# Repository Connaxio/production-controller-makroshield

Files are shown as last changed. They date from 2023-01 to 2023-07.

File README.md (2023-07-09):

# Production Controller makroShield
The Production Controller makroShield (PCM) is a modular controller designed to operate 24 V devices with the help of connected and remote sensors.

The PCM has a mikroBUS socket that works with Espoir, our Power over Ethernet devboard, to provide remote control, as well as advanced functionalities through node-red and Home Assistant. Simpler control can be achieved by directly programming Espoir.

Originally designed to operate greenhouses and irrigation valves, it can be adapted to many different kinds of small productions and climate control due to its modular nature.

2 drivers are available with the PCM: a 2-ways driver for bidirectional motors, and a 1-way, AC/DC controller for other devices, like valves, fans, and unidirectional motors. Up to 15 drivers can be connected simultaneously, and scheduled to use up to 350 Watts of power at a time.

Being modular makes the PCM easy to repair and upgrade, and helps reduce cost for smaller operations.

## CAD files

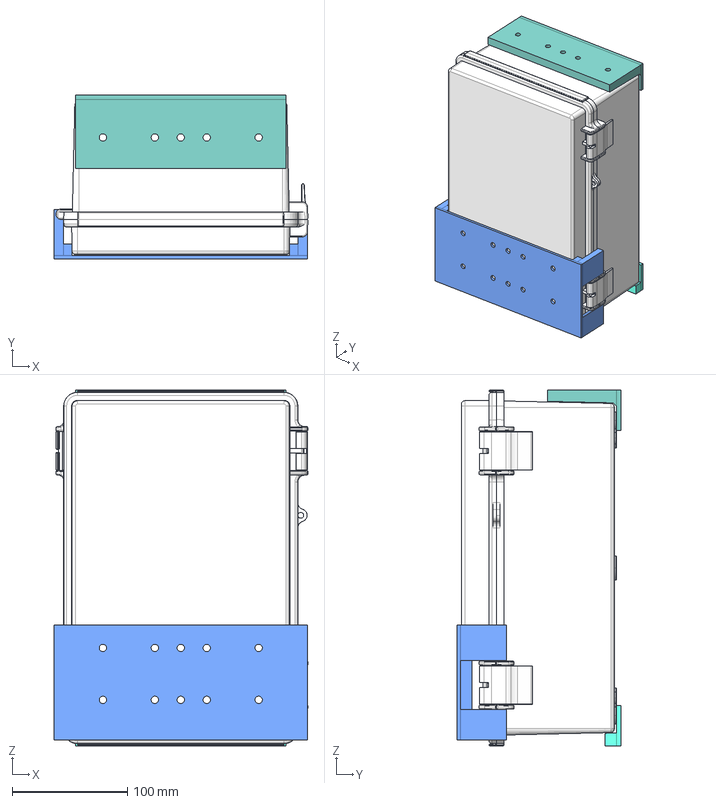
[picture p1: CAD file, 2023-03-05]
3d/piercing_guide.FCStd
219.9 x 142.5 x 308.6 mm
Latch-med-4mm
Latch-med-4mm001
NBF-32016-B
NBF-32016-C

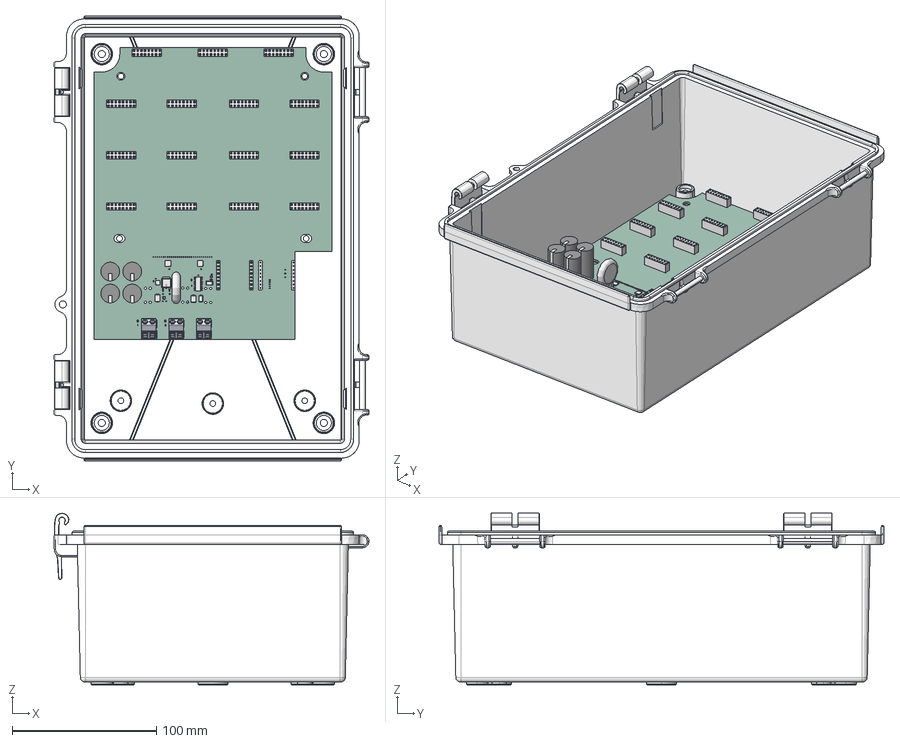
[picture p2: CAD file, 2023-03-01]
3d/3d_fit.FCStd
218.4 x 308.6 x 119.0 mm
Latch-med-4mm
Latch-med-4mm001
NBF-32016-B
production_controller_makroshield PCB

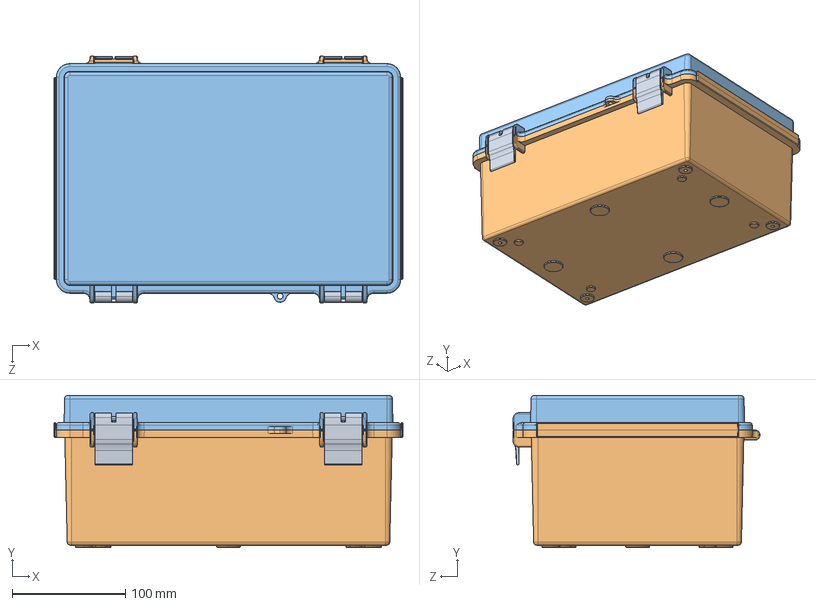
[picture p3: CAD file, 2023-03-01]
3d/NBF-32016.STEP
308.6 x 134.5 x 218.4 mm
Latch-med-4mm x 2
NBF-32016-B
NBF-32016-C

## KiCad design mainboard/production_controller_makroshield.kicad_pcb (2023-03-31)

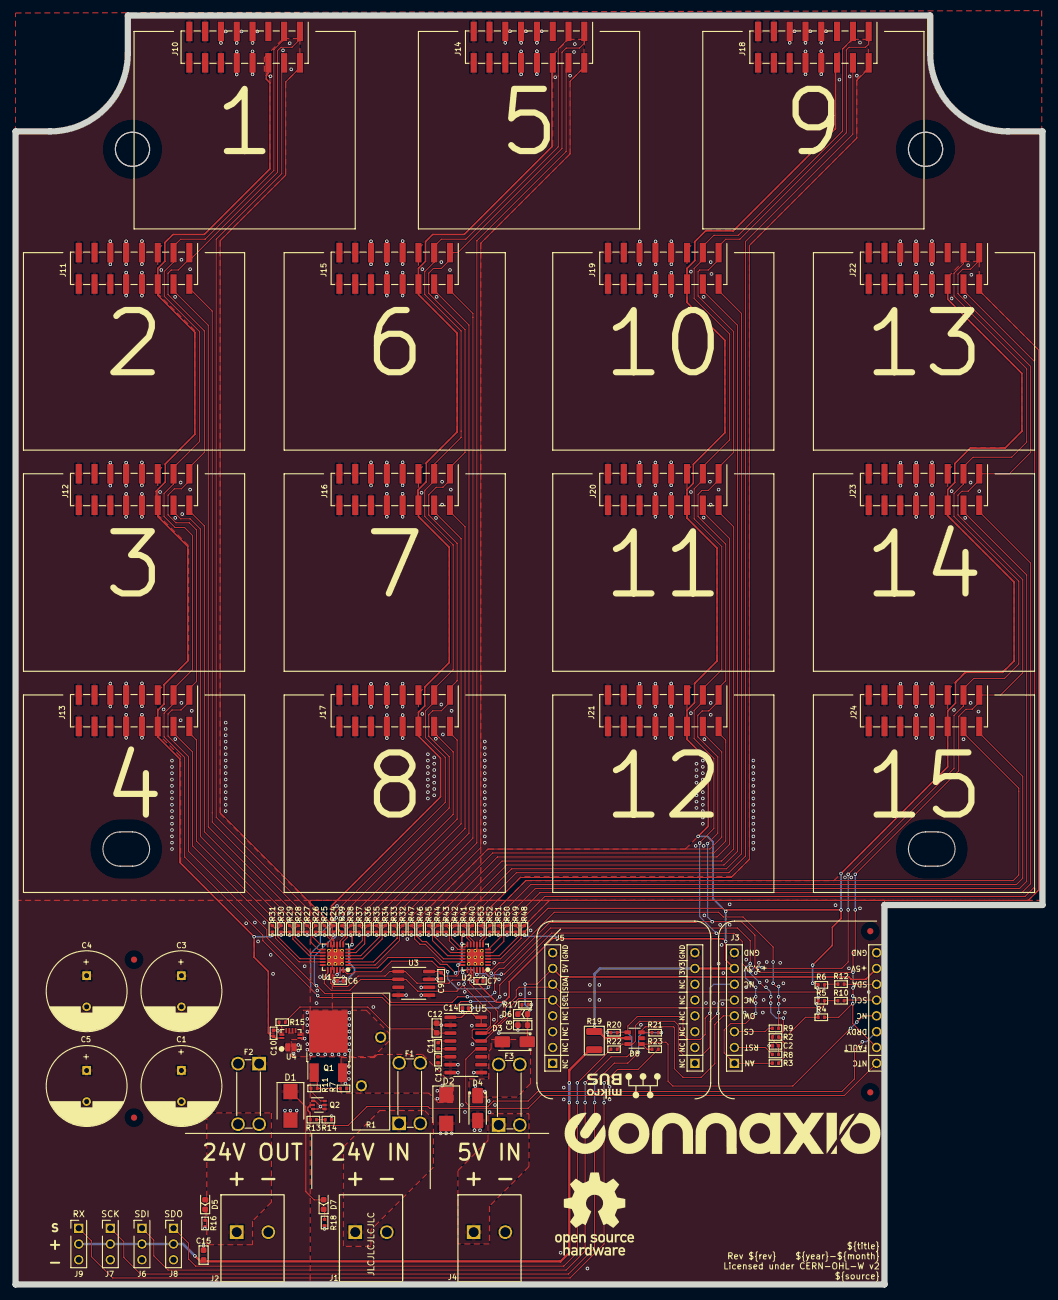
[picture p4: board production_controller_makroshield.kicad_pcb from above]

Board: 2 copper layers, 165.1 x 204.0 mm, 118 parts (1 on the bottom side), 72 nets.

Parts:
C1, C3, C4, C5: CAP_AE_1MF_50V_TH_12.5MM; CAPAE_RAD_D12.5_H26.5_P5
C2, C6, C7, C9, C10, C11, C13, C14: CAP_CER_100NF_25V_0402; CAP_CER_0402_1005M
C8, C12, C15: CAP_CER_22UF_10V_0603; CAP_CER_0603_1608M
D1, D2: DIO_TVS_24V_UNI_SMB; DO-124AA_SMB
D3: DIO_SBD_100V_3A_SMA; DO-214AC_SMA
D4: DIO_TVS_5V_UNI_SMA; DO-214AC_SMA
D5, D6, D7: DIO_LED_GREEN_150060GS75000; LED_0603_1608M
D8: DIO_TVS_SRV05-4HTG; SOT-23-6
F1, F2, F3: FUS_BLADE_MINI_3588-1
F4, F5, F6, F7: FID_1X3
J1, J2, J4: CON_TERM_BLK_1X2_TB008A-508-02BE
J3: CON_HDR_MIKROBUS_ADDON_TH
J5: CON_HDR_MIKROBUS_SOCKET_TH
J6, J7, J8, J9: CON_HDR_100MILS_M_TH_1X3
J10, J11, J12, J13, J14, J15, J16, J17, J18, J19, J20, J21, J22, J23, J24: CON_CONNAXIO_MOTOR_DRIVER
MTH1, MTH2: MTH_M5_NPTH
MTH3, MTH4: MTH_SLOT_M5_2MM_NPTH
Q1: TRX_PMOS_AOD4189; TO-252-3
Q2: TRX_2NPN_BC846S,115; SOT-363_SC-70-6
R1: NTC_SL22 2R018; RV_DISC_D22_W6_P7.8
R2, R3, R4, R7, R11, R13, R14, R24, R25, R26, R27, R28, R29, R30, R31, R32, R33, R34, R35, R36, R37, R38, R39, R40, R41, R42, R43, R44, R45, R46, R47, R48, R49, R50, R51, R52, R53: RES_12.4KΩ_1%_0402; RES_0402_1005M
R5, R6, R15, R16, R18: RES_5.10KΩ_1%_0402; RES_0402_1005M
R8, R9, R10, R12, R20, R21, R22, R23: RES_226Ω_1%_0402; RES_0402_1005M
R17: RES_1.00KΩ_1%_0402; RES_0402_1005M
R19: PTC_SMD1210B010TF; RES_1210_3225M
U1, U2: IO_EXP_PI4IOE5V6416ZDEX; QFN-24_4x4_P0.5_EP2.7X2.7
U3: SEN_TEMP_TMP1075DR; SOIC-8_3.9x4.9_P1.27
U4: SEN_CUR_ACS711KEXLT-31AB-T; QFN-12_CUR_SEN_ACS7
U5: ADC_NAU7802SGI; SOIC-16_3.9X9.9_P1.27

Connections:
+3.3V: C6.1, C7.1, C9.1, C10.1, C14.1, D8.5, J3.7 (+3.3V), J5.7 (+3.3V), J10.6 (3.3V), J11.6 (3.3V), J12.6 (3.3V), J13.6 (3.3V), J14.6 (3.3V), J15.6 (3.3V), J16.6 (3.3V), J17.6 (3.3V), J18.6 (3.3V), J19.6 (3.3V), J20.6 (3.3V), J21.6 (3.3V), J22.6 (3.3V), J23.6 (3.3V), J24.6 (3.3V), R2.1, R3.1, R4.1, R5.1, R6.1, R19.1, R24.1, R25.1, R26.1, R27.1, R28.1, R29.1, R30.1, R31.1, R32.1, R33.1, R34.1, R35.1, R36.1, R37.1, R38.1, R39.1, R40.1, R41.1, R42.1, R43.1, R44.1, R45.1, R46.1, R47.1, R48.1, R49.1, R50.1, R51.1, R52.1, R53.1, U1.21 (VDDP), U1.23 (VDDI2C), U2.18 (ADDR), U2.21 (VDDP), U2.23 (VDDI2C), U3.8 (V+), U4.12 (VCC), U5.1 (REFP), U5.15 (DVDD), U5.16 (AVDD)
+5V: C8.1, D3.1 (K), D6.2 (A), J3.15 (+5V), J5.15 (+5V)
+24VDC: C1.1, C3.1, C4.1, C5.1, D1.1 (K), D7.2 (A), F2.1, F2.2, J10.12 (VDrive), J10.13 (VDrive), J10.14 (VDrive), J10.15 (VDrive), J10.16 (VDrive), J11.12 (VDrive), J11.13 (VDrive), J11.14 (VDrive), J11.15 (VDrive), J11.16 (VDrive), J12.12 (VDrive), J12.13 (VDrive), J12.14 (VDrive), J12.15 (VDrive), J12.16 (VDrive), J13.12 (VDrive), J13.13 (VDrive), J13.14 (VDrive), J13.15 (VDrive), J13.16 (VDrive), J14.12 (VDrive), J14.13 (VDrive), J14.14 (VDrive), J14.15 (VDrive), J14.16 (VDrive), J15.12 (VDrive), J15.13 (VDrive), J15.14 (VDrive), J15.15 (VDrive), J15.16 (VDrive), J16.12 (VDrive), J16.13 (VDrive), J16.14 (VDrive), J16.15 (VDrive), J16.16 (VDrive), J17.12 (VDrive), J17.13 (VDrive), J17.14 (VDrive), J17.15 (VDrive), J17.16 (VDrive), J18.12 (VDrive), J18.13 (VDrive), J18.14 (VDrive), J18.15 (VDrive), J18.16 (VDrive), J19.12 (VDrive), J19.13 (VDrive), J19.14 (VDrive), J19.15 (VDrive), J19.16 (VDrive), J20.12 (VDrive), J20.13 (VDrive), J20.14 (VDrive), J20.15 (VDrive), J20.16 (VDrive), J21.12 (VDrive), J21.13 (VDrive), J21.14 (VDrive), J21.15 (VDrive), J21.16 (VDrive), J22.12 (VDrive), J22.13 (VDrive), J22.14 (VDrive), J22.15 (VDrive), J22.16 (VDrive), J23.12 (VDrive), J23.13 (VDrive), J23.14 (VDrive), J23.15 (VDrive), J23.16 (VDrive), J24.12 (VDrive), J24.13 (VDrive), J24.14 (VDrive), J24.15 (VDrive), J24.16 (VDrive), U4.1 (IP+), U4.2 (IP+)
/24V_OUT: D5.2 (A), F2.3, F2.4, J2.1
/CS+: Q1.3 (D), R1.2, U4.3 (IP-), U4.4 (IP-)
/DRDY: J3.11 (TX), U5.12 (DRDY)
/I2C_SCL: J5.13 (SCL), R5.2, R10.2, U1.19 (SCL), U2.19 (SCL), U3.2 (SCL), U5.13 (SCLK)
/I2C_SDA: J5.14 (SDA), R6.2, R12.2, U1.20 (SDA), U2.20 (SDA), U3.1 (SDA), U5.14 (SDIO)
/INT_IO: J3.1 (AN), R3.2, U1.22 (~INT), U2.22 (~INT)
/IO_RX: D8.1, J3.12 (RX), R23.1
/IO_SCK: D8.3, J3.4 (SCK), R21.1
/IO_SDI: D8.4, J3.6 (SDI), R20.1
/IO_SDO: D8.6, J3.5 (SDO), R22.1
/NTC_BYPASS: J3.9 (PWM), R13.1, R14.1
/RST_IO: R9.1, U1.24 (~RESET), U2.24 (~RESET)
CTRLA1: J10.2 (~CTRLA), R24.2, U1.10 (P1_0)
CTRLA2: J11.2 (~CTRLA), R26.2, U1.12 (P1_2)
CTRLA3: J12.2 (~CTRLA), R28.2, U1.14 (P1_4)
CTRLA4: J13.2 (~CTRLA), R30.2, U1.16 (P1_6)
CTRLA5: J14.2 (~CTRLA), R32.2, U1.1 (P0_0)
CTRLA6: J15.2 (~CTRLA), R34.2, U1.3 (P0_2)
CTRLA7: J16.2 (~CTRLA), R36.2, U1.5 (P0_4)
CTRLA8: J17.2 (~CTRLA), R38.2, U1.7 (P0_6)
CTRLA9: J18.2 (~CTRLA), R40.2, U2.10 (P1_0)
CTRLA10: J19.2 (~CTRLA), R42.2, U2.12 (P1_2)
CTRLA11: J20.2 (~CTRLA), R44.2, U2.14 (P1_4)
CTRLA12: J21.2 (~CTRLA), R46.2, U2.16 (P1_6)
CTRLA13: J22.2 (~CTRLA), R48.2, U2.3 (P0_2)
CTRLA14: J23.2 (~CTRLA), R50.2, U2.5 (P0_4)
CTRLA15: J24.2 (~CTRLA), R52.2, U2.7 (P0_6)
CTRLB1: J10.4 (~CTRLB), R25.2, U1.11 (P1_1)
CTRLB2: J11.4 (~CTRLB), R27.2, U1.13 (P1_3)
CTRLB3: J12.4 (~CTRLB), R29.2, U1.15 (P1_5)
CTRLB4: J13.4 (~CTRLB), R31.2, U1.17 (P1_7)
CTRLB5: J14.4 (~CTRLB), R33.2, U1.2 (P0_1)
CTRLB6: J15.4 (~CTRLB), R35.2, U1.4 (P0_3)
CTRLB7: J16.4 (~CTRLB), R37.2, U1.6 (P0_5)
CTRLB8: J17.4 (~CTRLB), R39.2, U1.8 (P0_7)
CTRLB9: J18.4 (~CTRLB), R41.2, U2.11 (P1_1)
CTRLB10: J19.4 (~CTRLB), R43.2, U2.13 (P1_3)
CTRLB11: J20.4 (~CTRLB), R45.2, U2.15 (P1_5)
CTRLB12: J21.4 (~CTRLB), R47.2, U2.17 (P1_7)
CTRLB13: J22.4 (~CTRLB), R49.2, U2.4 (P0_3)
CTRLB14: J23.4 (~CTRLB), R51.2, U2.6 (P0_5)
CTRLB15: J24.4 (~CTRLB), R53.2, U2.8 (P0_7)
FAULT: J3.10 (INT), J10.1 (~FAULT), J11.1 (~FAULT), J12.1 (~FAULT), J13.1 (~FAULT), J14.1 (~FAULT), J15.1 (~FAULT), J16.1 (~FAULT), J17.1 (~FAULT), J18.1 (~FAULT), J19.1 (~FAULT), J20.1 (~FAULT), J21.1 (~FAULT), J22.1 (~FAULT), J23.1 (~FAULT), J24.1 (~FAULT), R4.2
GND: C1.2, C2.2, C3.2, C4.2, C5.2, C6.2, C7.2, C8.2, C9.2, C10.2, C12.2, C13.2, C14.2, C15.2, D1.2 (A), D2.2 (A), D4.2 (A), D8.2, J1.2, J2.2, J3.8 (GND), J3.16 (GND), J4.2, J5.8 (GND), J5.16 (GND), J6.3, J7.3, J8.3, J9.3, J10.7 (GND), J10.8 (GND), J10.9 (GND), J10.10 (GND), J10.11 (GND), J11.7 (GND), J11.8 (GND), J11.9 (GND), J11.10 (GND), J11.11 (GND), J12.7 (GND), J12.8 (GND), J12.9 (GND), J12.10 (GND), J12.11 (GND), J13.7 (GND), J13.8 (GND), J13.9 (GND), J13.10 (GND), J13.11 (GND), J14.7 (GND), J14.8 (GND), J14.9 (GND), J14.10 (GND), J14.11 (GND), J15.7 (GND), J15.8 (GND), J15.9 (GND), J15.10 (GND), J15.11 (GND), J16.7 (GND), J16.8 (GND), J16.9 (GND), J16.10 (GND), J16.11 (GND), J17.7 (GND), J17.8 (GND), J17.9 (GND), J17.10 (GND), J17.11 (GND), J18.7 (GND), J18.8 (GND), J18.9 (GND), J18.10 (GND), J18.11 (GND), J19.7 (GND), J19.8 (GND), J19.9 (GND), J19.10 (GND), J19.11 (GND), J20.7 (GND), J20.8 (GND), J20.9 (GND), J20.10 (GND), J20.11 (GND), J21.7 (GND), J21.8 (GND), J21.9 (GND), J21.10 (GND), J21.11 (GND), J22.7 (GND), J22.8 (GND), J22.9 (GND), J22.10 (GND), J22.11 (GND), J23.7 (GND), J23.8 (GND), J23.9 (GND), J23.10 (GND), J23.11 (GND), J24.7 (GND), J24.8 (GND), J24.9 (GND), J24.10 (GND), J24.11 (GND), Q2.1 (E1), Q2.3 (C2), Q2.4 (E2), Q2.5 (B2), R14.2, R16.2, R17.2, R18.2, U1.9 (VSS), U1.18 (ADDR), U1.25 (PAD), U2.9 (VSS), U2.25 (PAD), U3.4 (GND), U3.5 (A2), U3.6 (A1), U3.7 (A0), U4.5 (GND), U5.2 (VIN1N), U5.7 (REFN), U5.8 (AVSS), U5.9 (DVSS)
unnamed: C11.1, U5.5 (VIN2P)
unnamed: C11.2, U5.4 (VIN2N)
unnamed: C12.1, R15.2, U5.3 (VIN1P)
unnamed: C13.1, U5.6 (VBG)
unnamed: D2.1 (K), F1.3, F1.4, Q1.2 (S), R1.1, R7.1
unnamed: D3.2 (A), D4.1 (K), F3.3, F3.4
unnamed: D5.1 (K), R16.1
unnamed: D6.1 (K), R17.1
unnamed: D7.1 (K), R18.1
unnamed: F1.1, F1.2, J1.1
unnamed: F3.1, F3.2, J4.1
unnamed: J3.2 (RST), R8.2
unnamed: J3.3 (CS), R9.2
unnamed: J3.13 (SCL), R10.1
unnamed: J3.14 (SDA), R12.1
unnamed: J6.1, R20.2
unnamed: J7.1, R21.2
unnamed: J8.1, R22.2
unnamed: C15.1, J6.2, J7.2, J8.2, J9.2, R19.2
unnamed: J9.1, R23.2
unnamed: Q1.1 (G), R7.2, R11.1
unnamed: Q2.2 (B1), R13.2
unnamed: Q2.6 (C1), R11.2
unnamed: R15.1, U4.11 (VIOUT)
RST_MOT: C2.1, J10.3 (~RESET), J11.3 (~RESET), J12.3 (~RESET), J13.3 (~RESET), J14.3 (~RESET), J15.3 (~RESET), J16.3 (~RESET), J17.3 (~RESET), J18.3 (~RESET), J19.3 (~RESET), J20.3 (~RESET), J21.3 (~RESET), J22.3 (~RESET), J23.3 (~RESET), J24.3 (~RESET), R2.2, R8.1

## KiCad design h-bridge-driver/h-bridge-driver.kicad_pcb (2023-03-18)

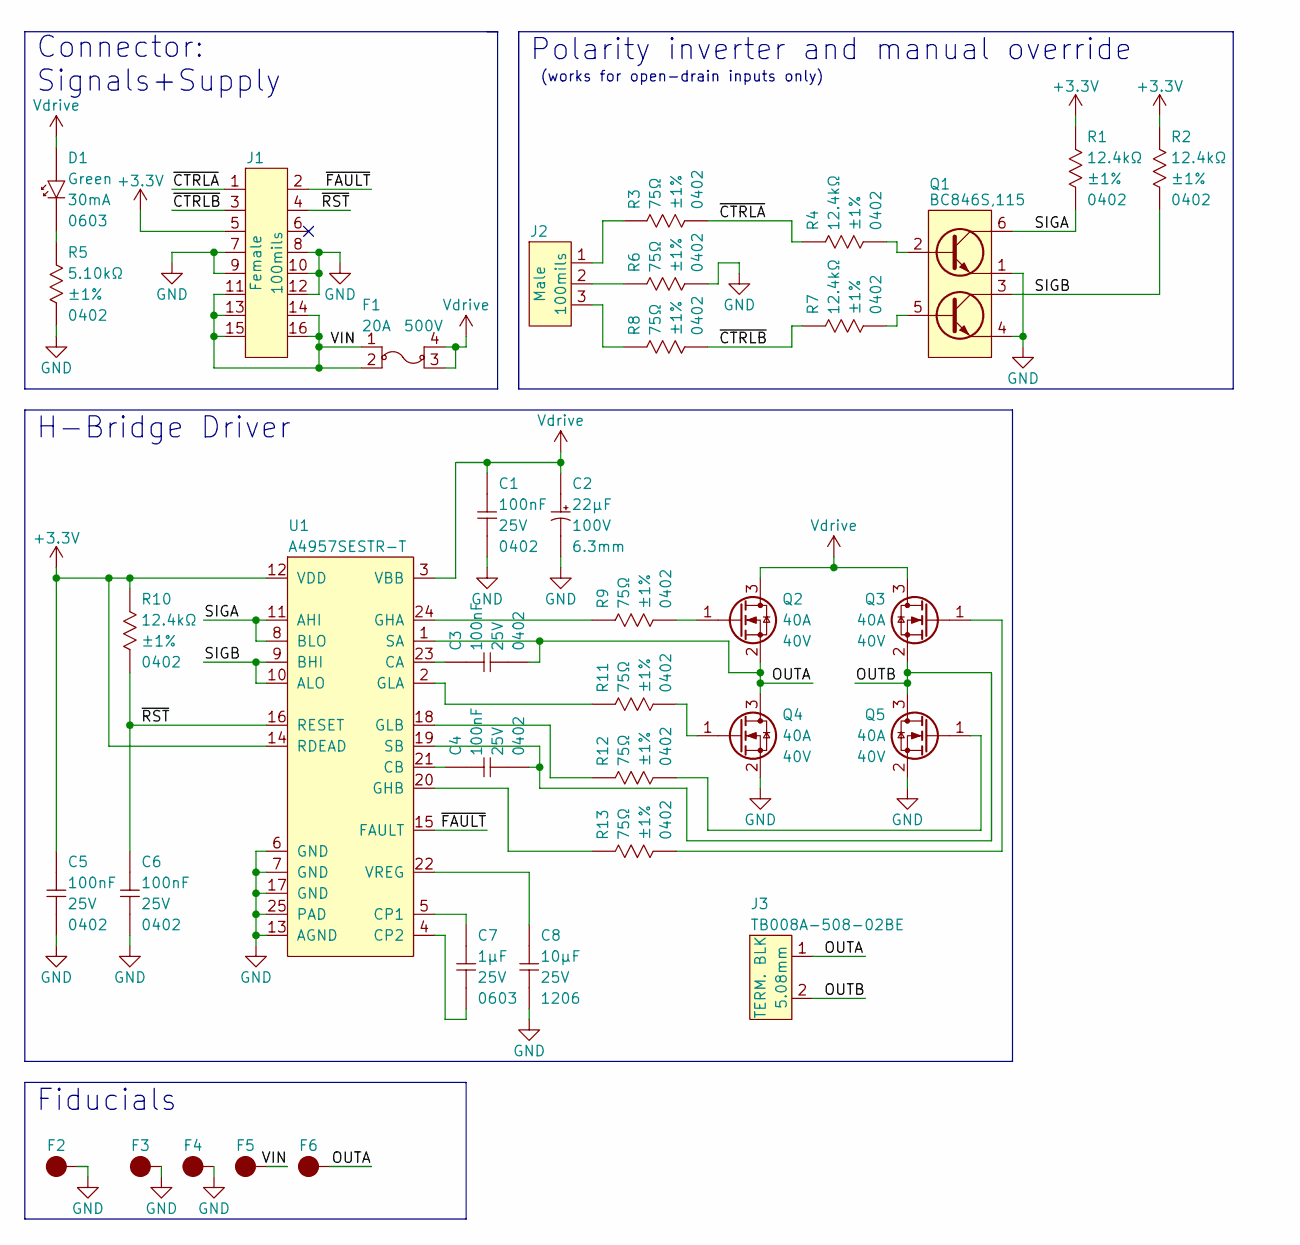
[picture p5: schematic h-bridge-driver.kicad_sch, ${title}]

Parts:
C1, C3, C4, C5, C6: CAP_CER_100NF_25V_0402; CAP_CER_0402_1005M; Tolerance ±10%; Voltage 25V; Manufacturer Part Number CL05A104KA5NNNC
C2: CAP_AE_22UF_100V_TH_6.3MM; CAP_AE_RAD_D6.3_H12.5_P2.5; Tolerance ±20%; Voltage 100V; Manufacturer Part Number ESK226M100AE3AA
C7: CAP_CER_1UF_25V_0603; CAP_CER_0603_1608M; Tolerance ±10%; Voltage 25V; Manufacturer Part Number CL10A105KA8NNNC
C8: CAP_CER_10UF_25V_1206; CAP_CER_1206_3216M; Tolerance ±10%; Voltage 25V; Manufacturer Part Number CL31A106KAHNNNE
D1: DIO_LED_GREEN_150060GS75000; LED_0603_1608M; Manufacturer Part Number 150060GS75000
F1: FUS_BLADE_MINI_3588-1; Voltage 500V; Manufacturer Part Number 3588-1
F2, F3, F4, F5, F6: FID_1X1
J1: CON_HDR_100MILS_F_TH_2X8; Voltage 350V
J2: CON_HDR_100MILS_M_TH_1X3; Voltage 350V
J3: CON_TERM_BLK_1X2_TB008A-508-02BE; Voltage 300V; Manufacturer Part Number TB008A-508-02BE
Q1: TRX_2NPN_BC846S,115; SOT-363_SC-70-6; Voltage 65V; Manufacturer Part Number BC846S,115
Q2, Q3, Q4, Q5: TRX_NMOS_PJD40N04_L2_00001; TO-252-3; Voltage 40V; Manufacturer Part Number PJD40N04_L2_00001
R1, R2, R4, R7, R10: RES_12.4KΩ_1%_0402; RES_0402_1005M; Tolerance ±1%; Voltage 50V; Manufacturer Part Number RMCF0402FT12K4
R3, R6, R8, R9, R11, R12, R13: RES_226Ω_1%_0402; RES_0402_1005M; Tolerance ±1%; Voltage 50V; Manufacturer Part Number RMCF0402FT75R0
R5: RES_5.10KΩ_1%_0402; RES_0402_1005M; Tolerance ±1%; Voltage 50V; Manufacturer Part Number RMCF0402FT5K10
U1: DRV_A4957SESTR-T; QFN-24_4x4_P0.5_EP2.7X2.7; Voltage 50V; Manufacturer Part Number A4957SESTR-T

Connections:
+3.3V: C5.1, J1.5, R1.1, R2.1, R10.1, U1.12 (VDD), U1.14 (RDEAD)
/OUTA: C3.2, F6.1, J3.1, Q2.2 (S), Q4.3 (D), U1.1 (SA)
/OUTB: C4.2, J3.2, Q3.2 (S), Q5.3 (D), U1.19 (SB)
/SIGA: Q1.6 (C1), R1.2, U1.8 (BLO), U1.11 (AHI)
/SIGB: Q1.3 (C2), R2.2, U1.9 (BHI), U1.10 (ALO)
/VIN: F1.1, F1.2, F5.1, J1.11, J1.13, J1.14, J1.15, J1.16
/~CTRLA: J1.1, R3.2, R4.1
/~CTRLB: J1.3, R7.1, R8.2
/~FAULT: J1.2, U1.15 (FAULT)
/~RST: C6.1, J1.4, R10.2, U1.16 (RESET)
GND: C1.2, C2.2, C5.2, C6.2, C8.2, F2.1, F3.1, F4.1, J1.7, J1.8, J1.9, J1.10, J1.12, Q1.1 (E1), Q1.4 (E2), Q4.2 (S), Q5.2 (S), R5.2, R6.2, U1.6 (GND), U1.7 (GND), U1.13 (AGND), U1.17 (GND), U1.25 (PAD)
unnamed: C3.1, U1.23 (CA)
unnamed: C4.1, U1.21 (CB)
unnamed: C7.1, U1.5 (CP1)
unnamed: C7.2, U1.4 (CP2)
unnamed: C8.1, U1.22 (VREG)
unnamed: D1.1 (K), R5.1
unnamed: J2.1, R3.1
unnamed: J2.2, R6.1
unnamed: J2.3, R8.1
unnamed: Q1.2 (B1), R4.2
unnamed: Q1.5 (B2), R7.2
unnamed: Q2.1 (G), R9.2
unnamed: Q3.1 (G), R13.2
unnamed: Q4.1 (G), R11.2
unnamed: Q5.1 (G), R12.2
unnamed: R9.1, U1.24 (GHA)
unnamed: R11.1, U1.2 (GLA)
unnamed: R12.1, U1.18 (GLB)
unnamed: R13.1, U1.20 (GHB)
Vdrive: C1.1, C2.1, D1.2 (A), F1.3, F1.4, Q2.3 (D), Q3.3 (D), U1.3 (VBB)

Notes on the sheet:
Fiducials
Polarity inverter and manual override
H-Bridge Driver
Connector: Signals+Supply
(works for open-drain inputs only)

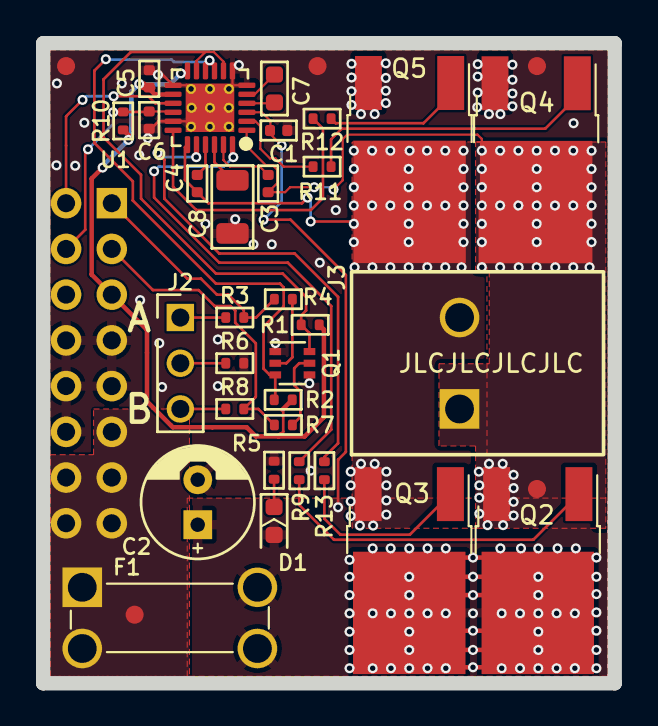
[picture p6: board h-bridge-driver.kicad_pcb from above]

Board: 2 copper layers, 31.8 x 35.6 mm, 37 parts (1 on the bottom side), 31 nets.

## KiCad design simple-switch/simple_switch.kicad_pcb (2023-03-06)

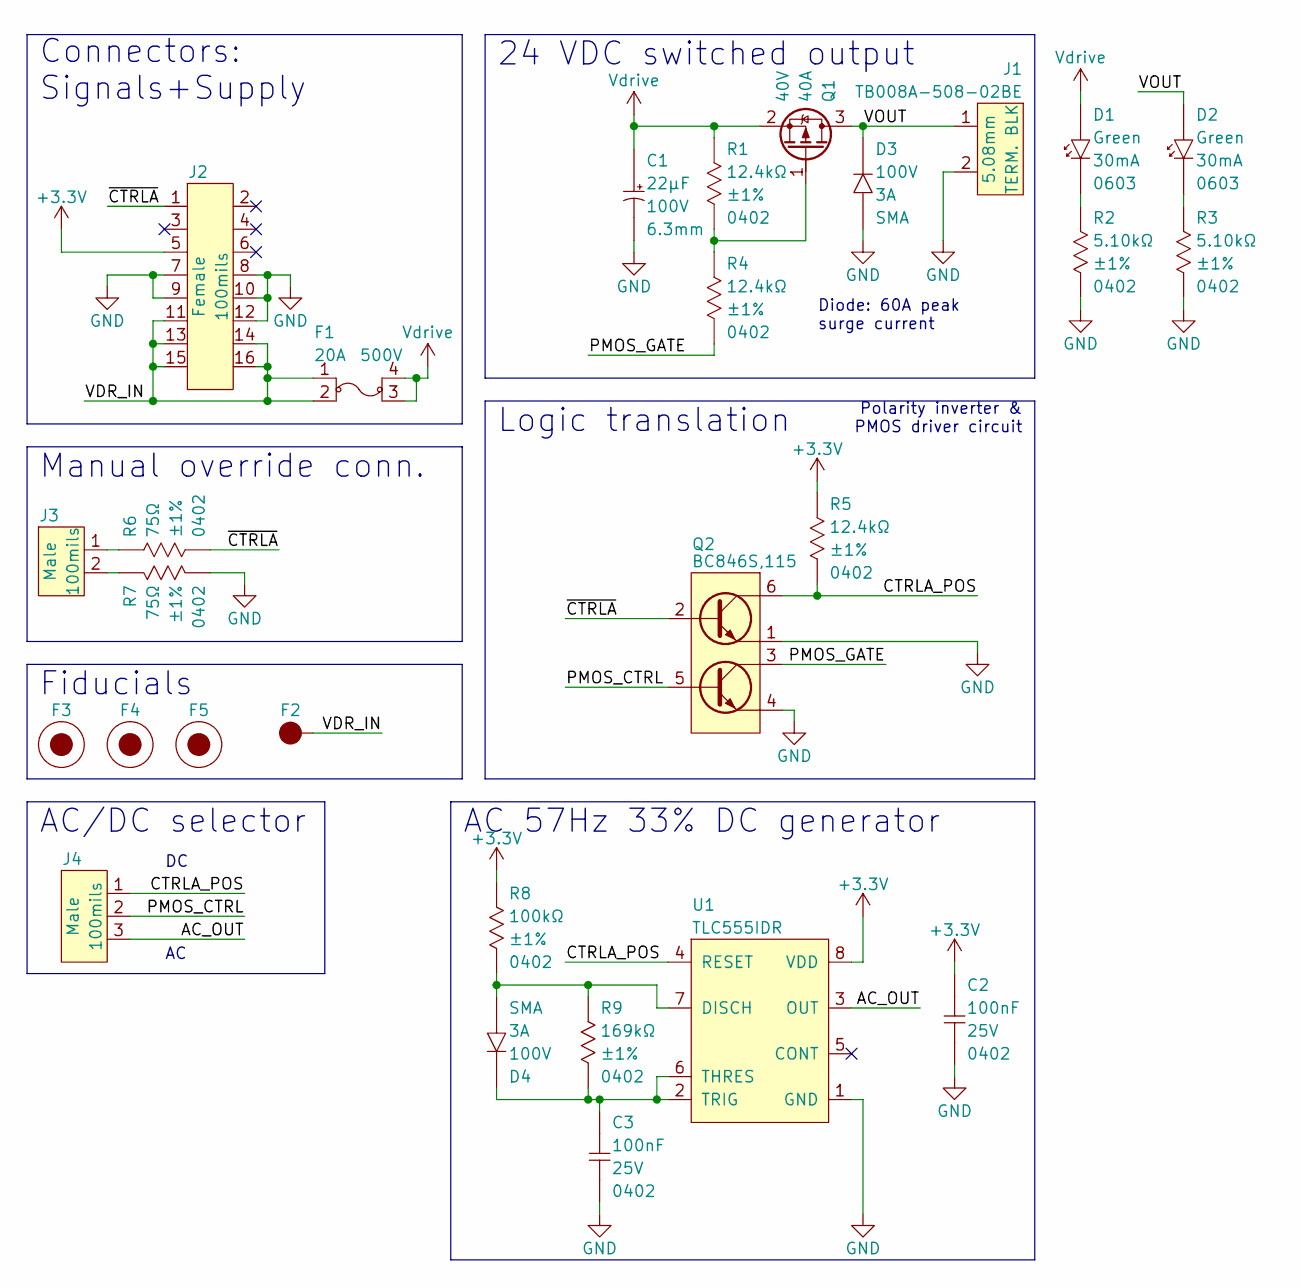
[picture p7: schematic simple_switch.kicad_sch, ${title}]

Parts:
C1: CAP_AE_22UF_100V_TH_6.3MM; CAP_AE_RAD_D6.3_H12.5_P2.5; Tolerance ±20%; Voltage 100V; Manufacturer Part Number ESK226M100AE3AA
C2, C3: CAP_CER_100NF_25V_0402; CAP_CER_0402_1005M; Tolerance ±10%; Voltage 25V; Manufacturer Part Number CL05A104KA5NNNC
D1, D2: DIO_LED_GREEN_150060GS75000; LED_0603_1608M; Manufacturer Part Number 150060GS75000
D3, D4: DIO_SBD_100V_3A_SMA; DO-214AC_SMA; Tolerance 60A; Voltage 100V; Manufacturer Part Number SL310A-TP
F1: FUS_BLADE_MINI_3588-1; Voltage 500V; Manufacturer Part Number 3588-1
F2: FID_1X1
F3, F4, F5: FID_1X3
J1: CON_TERM_BLK_1X2_TB008A-508-02BE; Voltage 300V; Manufacturer Part Number TB008A-508-02BE
J2: CON_HDR_100MILS_F_TH_2X8; Voltage 350V
J3: CON_HDR_100MILS_M_TH_1X2; Voltage 350V
J4: CON_HDR_100MILS_M_TH_1X3; Voltage 350V
Q1: TRX_PMOS_AOD4189; TO-252-3; Voltage 40V; Manufacturer Part Number AOD4189
Q2: TRX_2NPN_BC846S,115; SOT-363_SC-70-6; Voltage 65V; Manufacturer Part Number BC846S,115
R1, R4, R5: RES_12.4KΩ_1%_0402; RES_0402_1005M; Tolerance ±1%; Voltage 50V; Manufacturer Part Number RMCF0402FT12K4
R2, R3: RES_5.10KΩ_1%_0402; RES_0402_1005M; Tolerance ±1%; Voltage 50V; Manufacturer Part Number RMCF0402FT5K10
R6, R7: RES_226Ω_1%_0402; RES_0402_1005M; Tolerance ±1%; Voltage 50V; Manufacturer Part Number RMCF0402FT75R0
R8: RES_100KΩ_1%_0402; RES_0402_1005M; Tolerance ±1%; Voltage 50V; Manufacturer Part Number RMCF0402FT100K
R9: RES_169KΩ_1%_0402; RES_0402_1005M; Tolerance ±1%; Voltage 50V; Manufacturer Part Number RMCF0402FT169K
U1: TIMER_TLC555IDR; SOIC-8_3.9x4.9_P1.27; Voltage 3V - 15V; Manufacturer Part Number TLC555IDR

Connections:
+3.3V: C2.1, J2.5, R5.1, R8.1, U1.8 (VDD)
/AC_OUT: J4.3, U1.3 (OUT)
/CTRLA_POS: J4.1, Q2.6 (C1), R5.2, U1.4 (RESET)
/PMOS_CTRL: J4.2, Q2.5 (B2)
/PMOS_GATE: Q2.3 (C2), R4.2
/VDR_IN: F1.1, F1.2, F2.1, J2.11, J2.13, J2.14, J2.15, J2.16
/VOUT: D2.2 (A), D3.1 (K), J1.1, Q1.3 (D)
/~CTRLA: J2.1, Q2.2 (B1), R6.2
GND: C1.2, C2.2, C3.2, D3.2 (A), J1.2, J2.7, J2.8, J2.9, J2.10, J2.12, Q2.1 (E1), Q2.4 (E2), R2.2, R3.2, R7.2, U1.1 (GND)
unnamed: C3.1, D4.1 (K), R9.2, U1.2 (TRIG), U1.6 (THRES)
unnamed: D1.1 (K), R2.1
unnamed: D2.1 (K), R3.1
unnamed: D4.2 (A), R8.2, R9.1, U1.7 (DISCH)
unnamed: J3.1, R6.1
unnamed: J3.2, R7.1
unnamed: Q1.1 (G), R1.2, R4.1
Vdrive: C1.1, D1.2 (A), F1.3, F1.4, Q1.2 (S), R1.1

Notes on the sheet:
AC 57Hz 33% DC generator
Diode: 60A peak surge current
Polarity inverter & PMOS driver circuit
Logic translation
AC/DC selector
DC AC
Manual override conn.
Fiducials
24 VDC switched output
Connectors: Signals+Supply

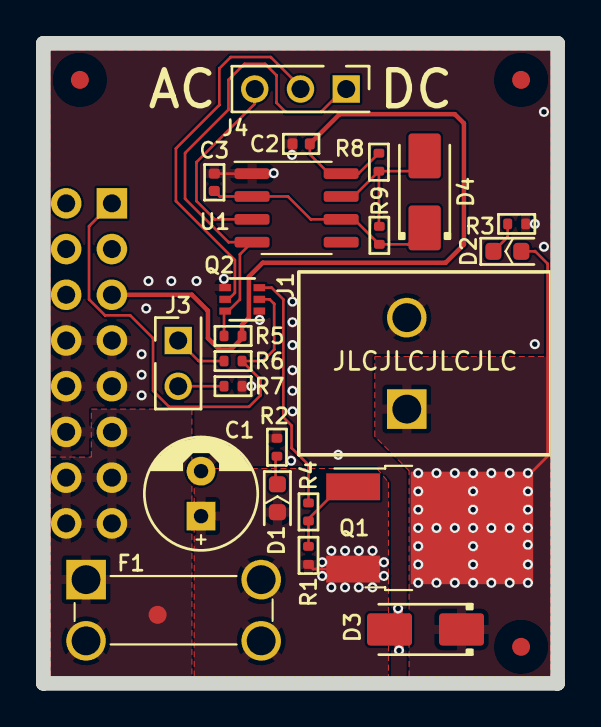
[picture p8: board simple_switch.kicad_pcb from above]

Board: 2 copper layers, 28.6 x 35.6 mm, 28 parts (1 on the bottom side), 17 nets.

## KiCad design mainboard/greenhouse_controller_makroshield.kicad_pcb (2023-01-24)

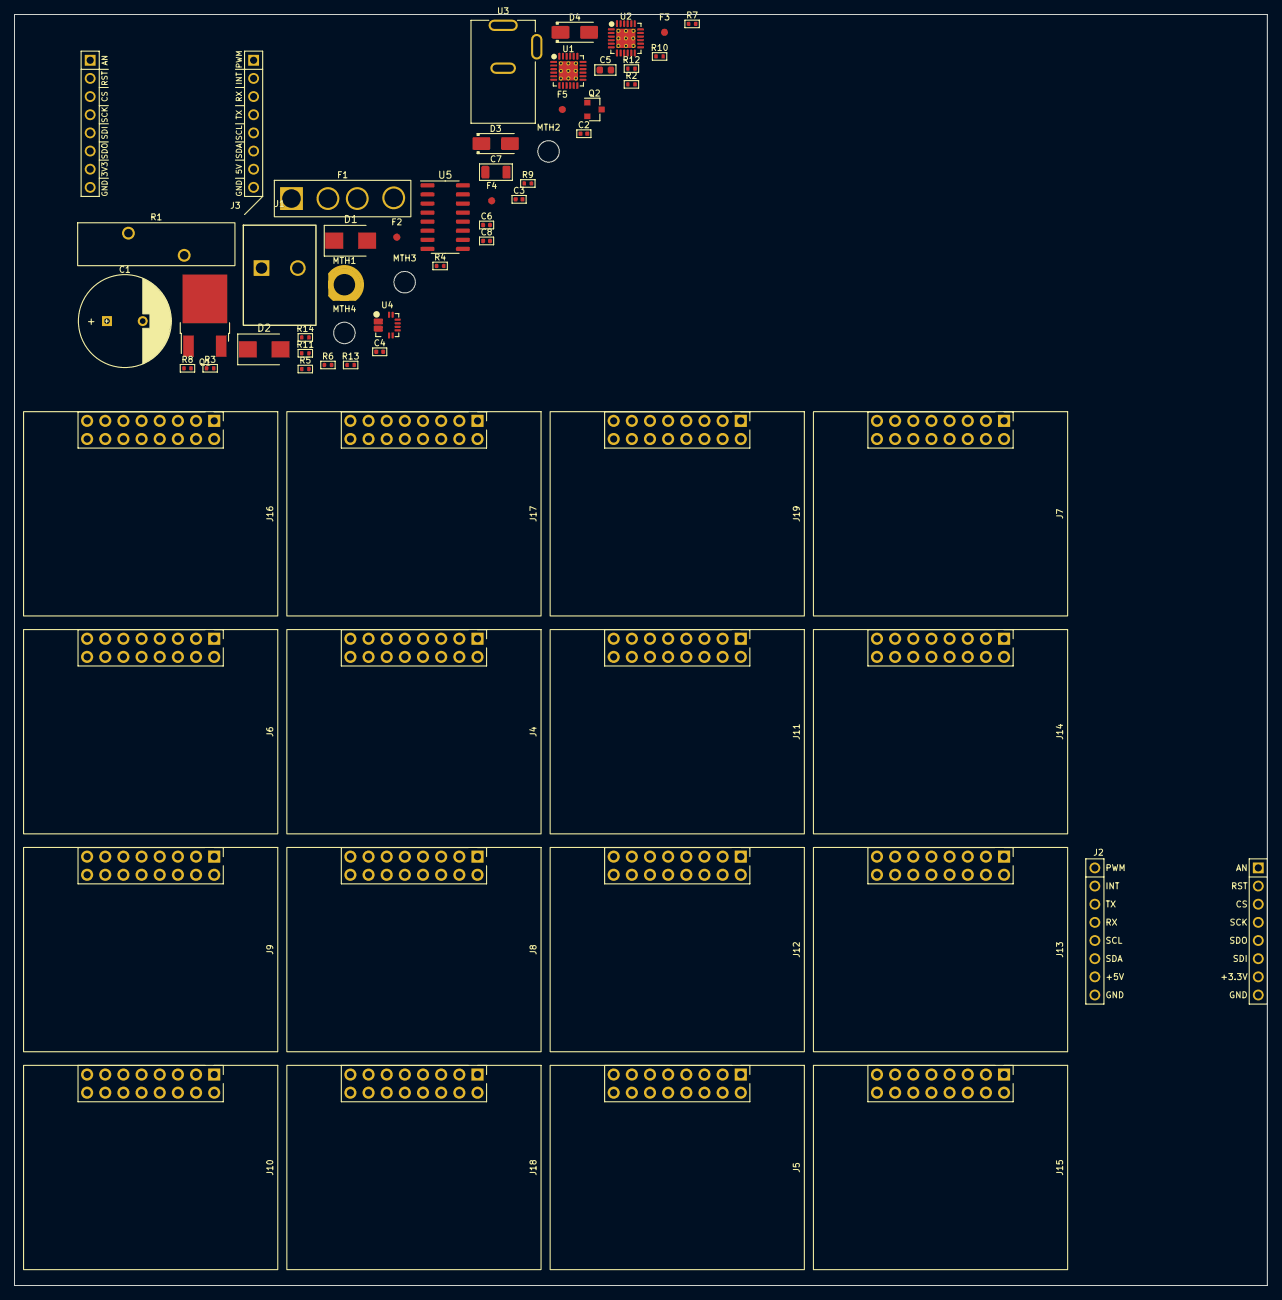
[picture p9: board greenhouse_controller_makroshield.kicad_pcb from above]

Board: 2 copper layers, 175.3 x 177.8 mm, 61 parts (1 on the bottom side), 57 nets, no tracks yet.

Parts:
C1: CAP_AE_1MF_50V_TH_12.5MM; CAPAE_RAD_D12.5_H26.5_P5
C2, C3, C4, C6, C8: CAP_CER_100NF_25V_0402; CAP_CER_0402_1005M
C5: CAP_CER_22UF_10V_0603; CAP_CER_0603_1608M
C7: CAP_CER_10UF_25V_1206; CAP_CER_1206_3216M
D1, D2: DIO_TVS_24V_UNI_SMB; DO-124AA_SMB
D3: DIO_SBD_100V_3A_SMA; DO-214AC_SMA
D4: DIO_TVS_5V_UNI_SMA; DO-214AC_SMA
F1: FUS_BLADE_3522
F2, F3, F4, F5: FID_1X3
J1: CON_TERM_BLK_1X2_TB008A-508-02BE
J2: CON_HDR_MIKROBUS_ADDON_TH
J3: CON_HDR_MIKROBUS_SOCKET_TH
J4, J5, J6, J7, J8, J9, J10, J11, J12, J13, J14, J15, J16, J17, J18, J19: CON_CONNAXIO_MOTOR_DRIVER
MTH1: MTH_M2.5_PTH_CORNER
MTH2, MTH3, MTH4: MTH_M2.5_NPTH
Q1: TRX_PMOS_AOD4189; TO-252-3
Q2: TRX_NPN_MMBT3904-TP; SOT-23-3
R1: NTC_SL22 2R018; RV_DISC_D22_W6_P7.8
R2, R3, R4, R7, R10, R12, R14: RES_12.4KΩ_1%_0402; RES_0402_1005M
R5, R6, R11: RES_1.54KΩ_1%_0402; RES_0402_1005M
R8, R9: RES_226Ω_1%_0402; RES_0402_1005M
R13: RES_0Ω_0402; RES_0402_1005M
U1, U2: IO_EXP_PI4IOE5V6416ZDEX; QFN-24_4x4_P0.5_EP2.7X2.7
U3: CON_BARREL_2.1X5.5_PJ-002A
U4: SUN_CUR_ACS711KEXLT-31AB-T; QFN-12_CUR_SEN_ACS7
U5: ADC_NAU7802SGI; SOIC-16_3.9X9.9_P1.27

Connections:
+3.3V: C3.1, C4.1, C6.1, J2.7 (+3.3V), J3.7 (+3.3V), J4.6 (3.3V), J5.6 (3.3V), J6.6 (3.3V), J7.6 (3.3V), J8.6 (3.3V), J9.6 (3.3V), J10.6 (3.3V), J11.6 (3.3V), J12.6 (3.3V), J13.6 (3.3V), J14.6 (3.3V), J15.6 (3.3V), J16.6 (3.3V), J17.6 (3.3V), J18.6 (3.3V), J19.6 (3.3V), R2.1, R3.1, R4.1, R5.1, R6.1, U1.21 (VDDP), U1.23 (VDDI2C), U2.18 (ADDR), U2.21 (VDDP), U2.23 (VDDI2C), U4.12 (VCC), U5.1 (REFP), U5.15 (DVDD), U5.16 (AVDD)
+5V: C5.1, D3.1 (K), D4.1 (K), J2.15 (+5V), J3.15 (+5V)
+24VDC: C1.1, D1.1 (K), J4.12 (VDrive), J4.13 (VDrive), J4.14 (VDrive), J4.15 (VDrive), J4.16 (VDrive), J5.12 (VDrive), J5.13 (VDrive), J5.14 (VDrive), J5.15 (VDrive), J5.16 (VDrive), J6.12 (VDrive), J6.13 (VDrive), J6.14 (VDrive), J6.15 (VDrive), J6.16 (VDrive), J7.12 (VDrive), J7.13 (VDrive), J7.14 (VDrive), J7.15 (VDrive), J7.16 (VDrive), J8.12 (VDrive), J8.13 (VDrive), J8.14 (VDrive), J8.15 (VDrive), J8.16 (VDrive), J9.12 (VDrive), J9.13 (VDrive), J9.14 (VDrive), J9.15 (VDrive), J9.16 (VDrive), J10.12 (VDrive), J10.13 (VDrive), J10.14 (VDrive), J10.15 (VDrive), J10.16 (VDrive), J11.12 (VDrive), J11.13 (VDrive), J11.14 (VDrive), J11.15 (VDrive), J11.16 (VDrive), J12.12 (VDrive), J12.13 (VDrive), J12.14 (VDrive), J12.15 (VDrive), J12.16 (VDrive), J13.12 (VDrive), J13.13 (VDrive), J13.14 (VDrive), J13.15 (VDrive), J13.16 (VDrive), J14.12 (VDrive), J14.13 (VDrive), J14.14 (VDrive), J14.15 (VDrive), J14.16 (VDrive), J15.12 (VDrive), J15.13 (VDrive), J15.14 (VDrive), J15.15 (VDrive), J15.16 (VDrive), J16.12 (VDrive), J16.13 (VDrive), J16.14 (VDrive), J16.15 (VDrive), J16.16 (VDrive), J17.12 (VDrive), J17.13 (VDrive), J17.14 (VDrive), J17.15 (VDrive), J17.16 (VDrive), J18.12 (VDrive), J18.13 (VDrive), J18.14 (VDrive), J18.15 (VDrive), J18.16 (VDrive), J19.12 (VDrive), J19.13 (VDrive), J19.14 (VDrive), J19.15 (VDrive), J19.16 (VDrive), Q1.3 (D), R1.2
/24V_Neg: J1.2, U4.3 (IP-), U4.4 (IP-)
/DRDY: J2.11 (TX), U5.12 (DRDY)
/I2C_SCL: J2.13 (SCL), J3.13 (SCL), R5.2, U1.19 (SCL), U2.19 (SCL), U5.13 (SCLK)
/I2C_SDA: J2.14 (SDA), J3.14 (SDA), R6.2, U1.20 (SDA), U2.20 (SDA), U5.14 (SDIO)
/INT_IO: J2.1 (AN), R3.2, U1.22 (~INT), U2.22 (~INT)
/NTC_BYPASS: J2.9 (PWM), R11.1, R12.1
/RST_IO: R9.1, U1.24 (~RESET), U2.24 (~RESET)
CTRLA1: J4.2 (CTRLA), U1.1 (P0_0)
CTRLA2: J5.2 (CTRLA), U1.3 (P0_2)
CTRLA3: J6.2 (CTRLA), U1.5 (P0_4)
CTRLA4: J7.2 (CTRLA), U1.7 (P0_6)
CTRLA5: J8.2 (CTRLA), U1.10 (P1_0)
CTRLA6: J9.2 (CTRLA), U1.12 (P1_2)
CTRLA7: J10.2 (CTRLA), U1.14 (P1_4)
CTRLA8: J11.2 (CTRLA), U1.16 (P1_6)
CTRLA9: J12.2 (CTRLA), U2.1 (P0_0)
CTRLA10: J13.2 (CTRLA), U2.3 (P0_2)
CTRLA11: J14.2 (CTRLA), U2.5 (P0_4)
CTRLA12: J15.2 (CTRLA), U2.7 (P0_6)
CTRLA13: J16.2 (CTRLA), U2.10 (P1_0)
CTRLA14: J17.2 (CTRLA), U2.12 (P1_2)
CTRLA15: J18.2 (CTRLA), U2.14 (P1_4)
CTRLA16: J19.2 (CTRLA), U2.16 (P1_6)
CTRLB1: J4.4 (CTRLB), U1.2 (P0_1)
CTRLB2: J5.4 (CTRLB), U1.4 (P0_3)
CTRLB3: J6.4 (CTRLB), U1.6 (P0_5)
CTRLB4: J7.4 (CTRLB), U1.8 (P0_7)
CTRLB5: J8.4 (CTRLB), U1.11 (P1_1)
CTRLB6: J9.4 (CTRLB), U1.13 (P1_3)
CTRLB7: J10.4 (CTRLB), U1.15 (P1_5)
CTRLB8: J11.4 (CTRLB), U1.17 (P1_7)
CTRLB9: J12.4 (CTRLB), U2.2 (P0_1)
CTRLB10: J13.4 (CTRLB), U2.4 (P0_3)
CTRLB11: J14.4 (CTRLB), U2.6 (P0_5)
CTRLB12: J15.4 (CTRLB), U2.8 (P0_7)
CTRLB13: J16.4 (CTRLB), U2.11 (P1_1)
CTRLB14: J17.4 (CTRLB), U2.13 (P1_3)
CTRLB15: J18.4 (CTRLB), U2.15 (P1_5)
CTRLB16: J19.4 (CTRLB), U2.17 (P1_7)
FAULT: J2.10 (INT), J4.1 (FAULT), J5.1 (FAULT), J6.1 (FAULT), J7.1 (FAULT), J8.1 (FAULT), J9.1 (FAULT), J10.1 (FAULT), J11.1 (FAULT), J12.1 (FAULT), J13.1 (FAULT), J14.1 (FAULT), J15.1 (FAULT), J16.1 (FAULT), J17.1 (FAULT), J18.1 (FAULT), J19.1 (FAULT), R4.2
GND: C1.2, C2.2, C3.2, C4.2, C5.2, C6.2, C7.2, C8.2, D1.2 (A), D2.2 (A), D4.2 (A), J2.8 (GND), J2.16 (GND), J3.8 (GND), J3.16 (GND), J4.7 (GND), J4.8 (GND), J4.9 (GND), J4.10 (GND), J4.11 (GND), J5.7 (GND), J5.8 (GND), J5.9 (GND), J5.10 (GND), J5.11 (GND), J6.7 (GND), J6.8 (GND), J6.9 (GND), J6.10 (GND), J6.11 (GND), J7.7 (GND), J7.8 (GND), J7.9 (GND), J7.10 (GND), J7.11 (GND), J8.7 (GND), J8.8 (GND), J8.9 (GND), J8.10 (GND), J8.11 (GND), J9.7 (GND), J9.8 (GND), J9.9 (GND), J9.10 (GND), J9.11 (GND), J10.7 (GND), J10.8 (GND), J10.9 (GND), J10.10 (GND), J10.11 (GND), J11.7 (GND), J11.8 (GND), J11.9 (GND), J11.10 (GND), J11.11 (GND), J12.7 (GND), J12.8 (GND), J12.9 (GND), J12.10 (GND), J12.11 (GND), J13.7 (GND), J13.8 (GND), J13.9 (GND), J13.10 (GND), J13.11 (GND), J14.7 (GND), J14.8 (GND), J14.9 (GND), J14.10 (GND), J14.11 (GND), J15.7 (GND), J15.8 (GND), J15.9 (GND), J15.10 (GND), J15.11 (GND), J16.7 (GND), J16.8 (GND), J16.9 (GND), J16.10 (GND), J16.11 (GND), J17.7 (GND), J17.8 (GND), J17.9 (GND), J17.10 (GND), J17.11 (GND), J18.7 (GND), J18.8 (GND), J18.9 (GND), J18.10 (GND), J18.11 (GND), J19.7 (GND), J19.8 (GND), J19.9 (GND), J19.10 (GND), J19.11 (GND), Q2.2 (E), R12.2, R13.2, U1.9 (VSS), U1.18 (ADDR), U1.25 (PAD), U2.9 (VSS), U2.25 (PAD), U3.2, U3.3, U4.1 (IP+), U4.2 (IP+), U4.5 (GND), U5.2 (VIN1N), U5.4 (VIN2N), U5.5 (VIN2P), U5.7 (REFN), U5.8 (AVSS), U5.9 (DVSS)
unnamed: C7.1, R14.2, U5.3 (VIN1P)
unnamed: C8.1, U5.6 (VBG)
unnamed: D2.1 (K), F1.3, F1.4, Q1.2 (S), R1.1, R7.1
unnamed: D3.2 (A), U3.1
unnamed: F1.1, F1.2, J1.1
unnamed: J2.2 (RST), R8.2
unnamed: J2.3 (CS), R9.2
unnamed: MTH1.1, R13.1
unnamed: Q1.1 (G), R7.2, R10.1
unnamed: Q2.1 (B), R11.2
unnamed: Q2.3 (C), R10.2
unnamed: R14.1, U4.11 (VIOUT)
RST_MOT: C2.1, J4.3 (RESET), J5.3 (RESET), J6.3 (RESET), J7.3 (RESET), J8.3 (RESET), J9.3 (RESET), J10.3 (RESET), J11.3 (RESET), J12.3 (RESET), J13.3 (RESET), J14.3 (RESET), J15.3 (RESET), J16.3 (RESET), J17.3 (RESET), J18.3 (RESET), J19.3 (RESET), R2.2, R8.1

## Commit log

2023-01-18 Add license,create project
    [greenhouse_controller_makroshield.kicad_pcb, greenhouse_controller_makroshield.kicad_sch]
2023-01-19 WIP, add conntectors
    [greenhouse_controller_makroshield.kicad_sch]
2023-01-19 Finish 24VDC input
    [greenhouse_controller_makroshield.kicad_sch]
2023-01-20 Finish motor driver and add tentative switched output (TBC with valves)
    [greenhouse_controller_makroshield.kicad_sch]
2023-01-20 Split project in two parts: mainboard and motor driver boards
    [greenhouse_controller_makroshield.kicad_pcb, greenhouse_controller_makroshield.kicad_sch, h-bridge-driver.kicad_pcb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]
2023-01-22 Complete H bridge driver
    [greenhouse_controller_makroshield.kicad_sch, h-bridge-driver.kicad_pcb, h-bridge-driver.kicad_sch]
2023-01-23 Add IO expanders, add simple PMOS switch, add 5V TVS,
    [greenhouse_controller_makroshield.kicad_sch, h-bridge-driver.kicad_sch, simple_switch.kicad_pcb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]
2023-01-23 Add motor driver page and I2C proteciton adapter, current & temp sensor
    [greenhouse_controller_makroshield.kicad_pcb, greenhouse_controller_makroshield.kicad_sch, h-bridge-driver.kicad_pcb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]
2023-01-24 Move fuse to motor driver board Optimize board array schematic (hierarchical schematics)
    [greenhouse_controller_makroshield.kicad_pcb, greenhouse_controller_makroshield.kicad_sch, h-bridge-driver.kicad_pcb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]
2023-01-25 rename project, comple simple switch layout, fix thermal reliefs
    [h-bridge-driver.kicad_pcb, h-bridge-driver.kicad_sch, production_controller_makroshield.kicad_pcb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]
2023-01-29 Inverted motor controls for open-drain operation and manual switch override compatibility
    [h-bridge-driver.kicad_pcb, h-bridge-driver.kicad_sch, motor_driver_connector.kicad_sch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]
2023-01-31 Position drive rmodules, choose enclosure, shape PCB
    [motor_driver_connector.kicad_sch, motor_drivers.kicad_sch, production_controller_makroshield.kicad_pcb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]
2023-02-01 Routing mainboard
    [motor_driver_connector.kicad_sch, production_controller_makroshield.kicad_pcb, production_controller_makroshield.kicad_sch]
2023-02-02 DRC pass
    [h-bridge-driver.kicad_pcb, production_controller_makroshield.kicad_pcb, production_controller_makroshield.kicad_sch]
2023-02-14 Add high-current pathways and extra capacitors. DRC pass
    [motor_driver_connector.kicad_sch, production_controller_makroshield.kicad_pcb, production_controller_makroshield.kicad_sch]
2023-02-14 Add LEDs, fix NMOS, Add logos and infos on PCBs.
    [h-bridge-driver.kicad_pcb, h-bridge-driver.kicad_sch, motor_driver_connector.kicad_sch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]
2023-03-01 Add Enclosure piercing guide and fix h-bridge-driver NMOS pads.
    [3d_fit.FCStd, NBF-32016.STEP, h-bridge-driver.kicad_pcb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]
2023-03-05 Invert connectors (male/female) Replace TH connectors with SMD ones on mainboard Add 555 timer on simple-switch to generate 60 Hz Add jumper on simple-switch to select AC Add series I2C resistors on 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
    [h-bridge-driver.kicad_pcb, h-bridge-driver.kicad_sch, motor_driver_connector.kicad_sch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]
2023-03-06 Add flyback diode to simple-switch
    [simple_switch.kicad_pcb, simple_switch.kicad_sch]
2023-03-06 Add onboard temperature sensor Add connector for Analog / 1-wire / PWM sensor
    [motor_driver_connector.kicad_sch, production_controller_makroshield.kicad_pcb, production_controller_makroshield.kicad_sch]
2023-03-06 Add filter cap to current reading ADC
    [production_controller_makroshield.kicad_pcb, production_controller_makroshield.kicad_sch]
2023-03-31 Add 4 extra IOs (SVG connectors)
    [motor_driver_connector.kicad_sch, production_controller_makroshield.kicad_pcb, production_controller_makroshield.kicad_sch]

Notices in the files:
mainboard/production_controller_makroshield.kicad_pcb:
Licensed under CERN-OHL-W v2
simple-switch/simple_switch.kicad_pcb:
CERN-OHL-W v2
